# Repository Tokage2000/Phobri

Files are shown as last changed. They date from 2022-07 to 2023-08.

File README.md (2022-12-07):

# Phobri
Repository for a modification of the Phob motherboard to fit an Hori Pad GCC

Potential issues: <br />

LR pads are a bit too small, you may need to glue them/stick them in place if you plan to use them. <br />

You have to cut the inner top of the shell and the start button. <br />
 <br />

Cstick may be awkward to connect. <br />
 <br />

Phob repositories: https://github.com/PhobGCC

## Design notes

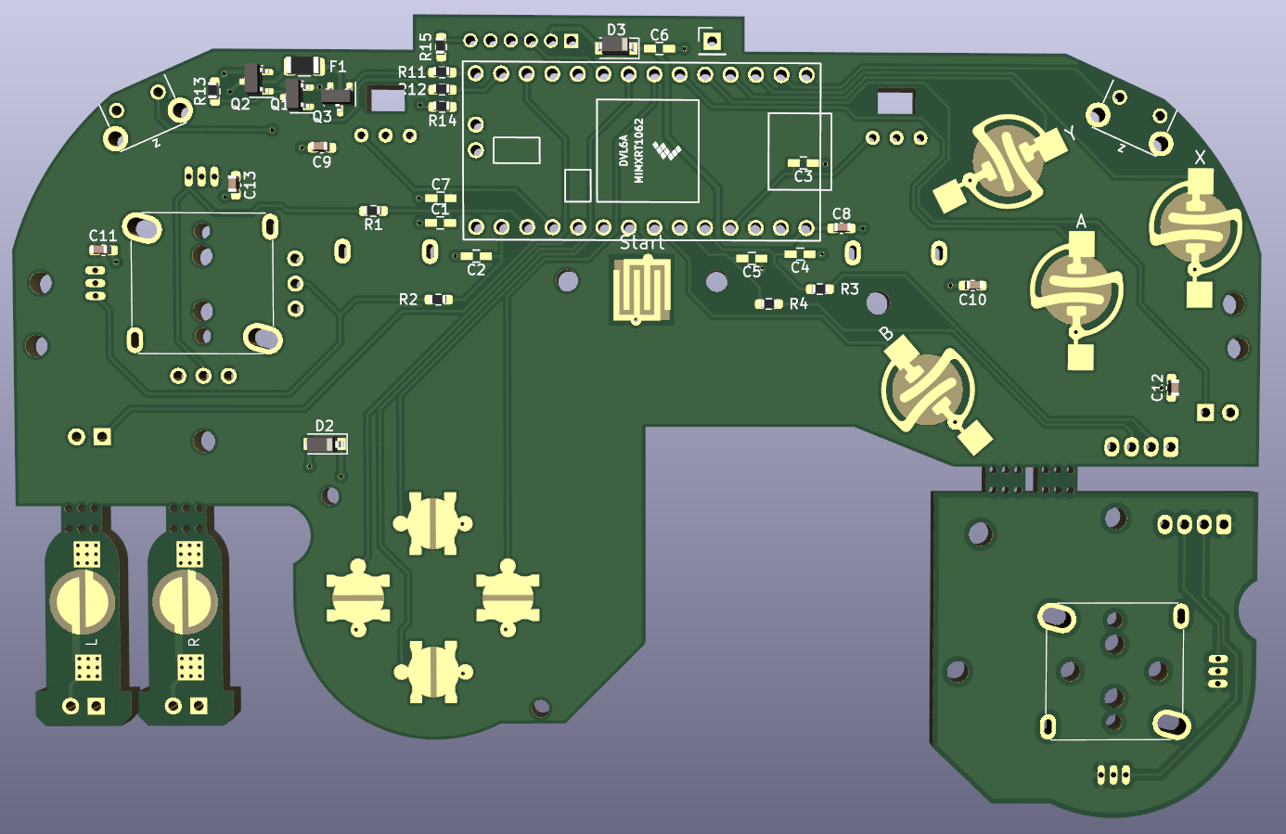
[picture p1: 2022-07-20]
Picture.PNG

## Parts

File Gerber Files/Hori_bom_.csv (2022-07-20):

C1 C2 C3 C4 C5 C7 | 0.047u | C1622 | 6 | https://lcsc.com/product-detail/Multilayer-Ceramic-Capacitors-MLCC-SMD-SMT_Samsung-Electro-Mechanics-CL10B473KB8NNNC_C1622.html
C8 C9 C10 C11 C12 C13 | 1u | C15849 | 6 | https://lcsc.com/product-detail/Multilayer-Ceramic-Capacitors-MLCC-SMD-SMT_Samsung-Electro-Mechanics-CL10A105KB8NNNC_C15849.html
C6 | 10u | C19702 | 1 | https://lcsc.com/product-detail/Multilayer-Ceramic-Capacitors-MLCC-SMD-SMT_Samsung-Electro-Mechanics-CL10A106KP8NNNC_C19702.html
D2 D3 | M7C | C8598 | 2 | https://lcsc.com/product-detail/Schottky-Barrier-Diodes-SBD_Changjiang-Electronics-Tech-CJ-B5819W-SL_C8598.html
F1 | Fuse | C69680 | 1 | https://lcsc.com/product-detail/Resettable-Fuses_TECHFUSE-nSMD020-30V_C69680.html
Q1 Q3 | Q_NMOS_GSD | C20917 | 2 | https://lcsc.com/product-detail/MOSFETs_Alpha-Omega-Semicon-AO3400A_C20917.html
Q2 | Q_PMOS_GDS | C15127 | 1 | https://lcsc.com/product-detail/MOSFETs_Alpha-Omega-Semicon-AO3401A_C15127.html
R11 R12 | 100R | C22775 | 2 | https://lcsc.com/product-detail/Chip-Resistor-Surface-Mount_UNI-ROYAL-Uniroyal-Elec-0603WAF1000T5E_C22775.html
R1 R2 R3 R4 | 2k | C22975 | 4 | https://lcsc.com/product-detail/Chip-Resistor-Surface-Mount_UNI-ROYAL-Uniroyal-Elec-0603WAF2001T5E_C22975.html
R13 R14 R15 | 10k | C25804 | 3 | https://lcsc.com/product-detail/Chip-Resistor-Surface-Mount_UNI-ROYAL-Uniroyal-Elec-0603WAF1002T5E_C25804.html

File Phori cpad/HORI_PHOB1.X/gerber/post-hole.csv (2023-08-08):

Designator | Footprint | Quantity | Value | LCSC Part #
C1, C2, C3 | C_0402_1005Metric | 3 | 100n | C1525
R1, R2 | R_0603_1608Metric_Pad0.98x0.95mm_HandSolder | 2 | 1.1k | C137780
R5, R6, R7, R8 | R_0603_1608Metric_Pad0.98x0.95mm_HandSolder | 4 | 5.6k | C114627
SW1 | SW-TH_L6.2-W6.2-P5.00 | 1 | C_left | C395225
SW2 | SW-TH_L6.2-W6.2-P5.00 | 1 | C_up | C395225
SW3 | SW-TH_L6.2-W6.2-P5.00 | 1 | C_down | C395225
SW4 | SW-TH_L6.2-W6.2-P5.00 | 1 | C_right | C395225

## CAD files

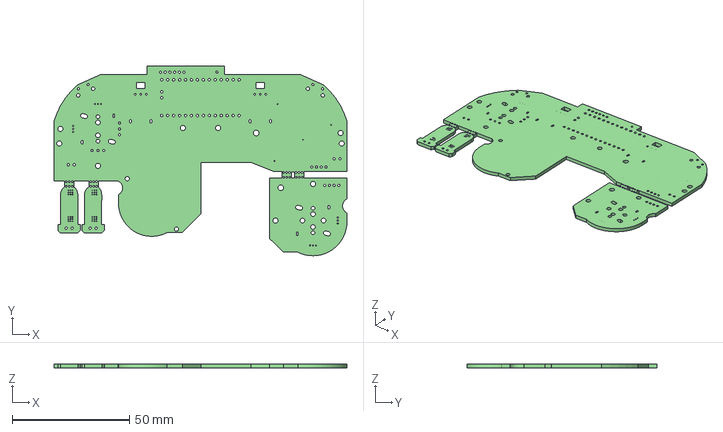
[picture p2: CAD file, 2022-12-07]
KiCad/PhobGCC.step
125.0 x 80.9 x 1.60 mm

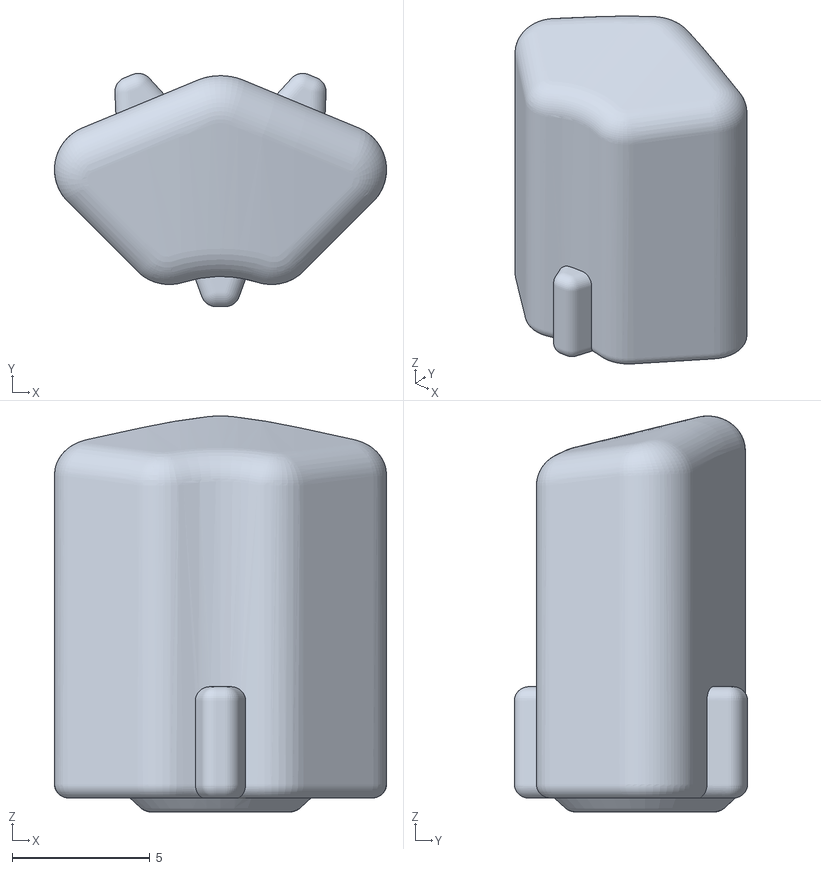
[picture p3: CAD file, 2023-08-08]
Phori cpad/1083v2x1-cpad_button_V2.stl
12.1 x 8.47 x 14.4

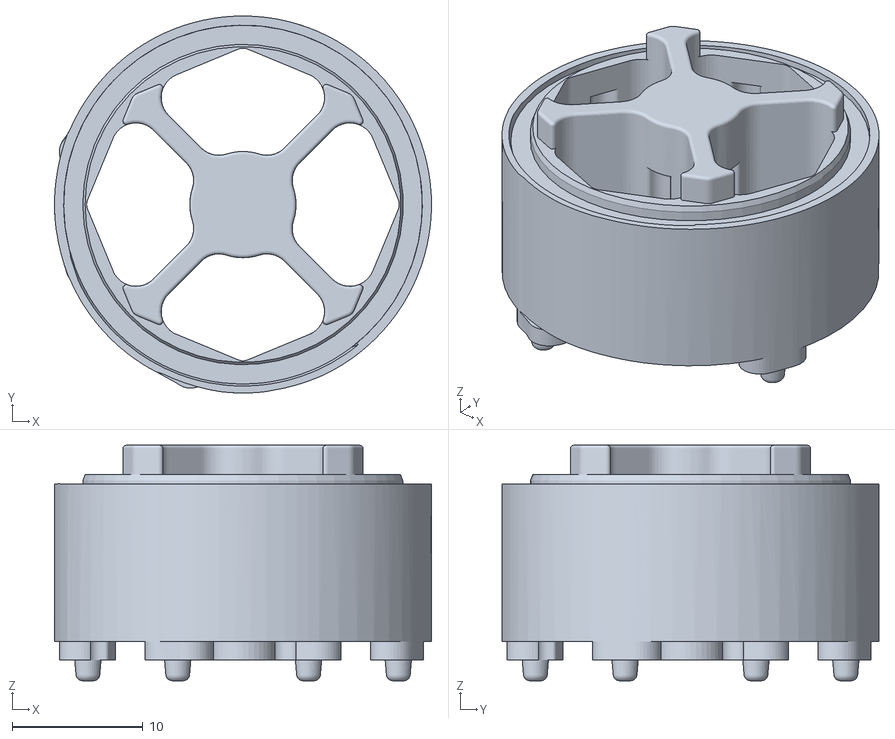
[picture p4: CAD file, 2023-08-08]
Phori cpad/1083-cpad_core.stl
28.8 x 28.8 x 18.0

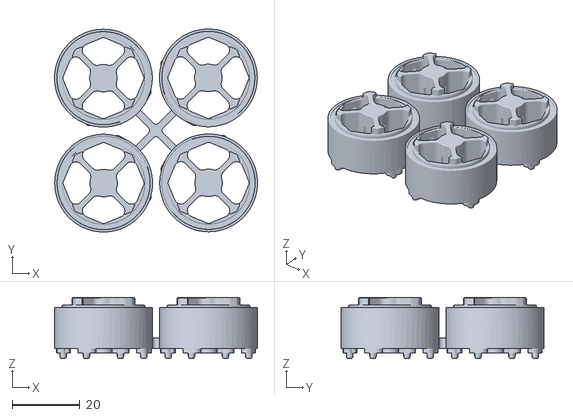
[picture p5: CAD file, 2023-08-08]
Phori cpad/1083x4-cpad_core_x4.stl
59.8 x 59.8 x 18.0

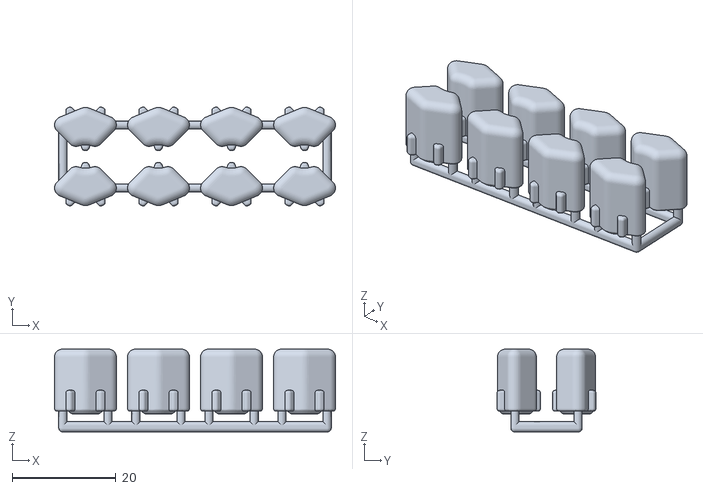
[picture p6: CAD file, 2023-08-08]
Phori cpad/1083 button x8-cpad_button_x8.stl
54.2 x 19.1 x 16.0

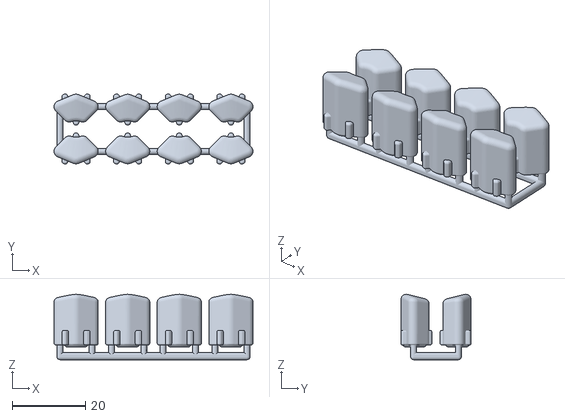
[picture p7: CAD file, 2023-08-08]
Phori cpad/1083v2x8-cpad_button_V2.stl
54.3 x 19.2 x 17.9

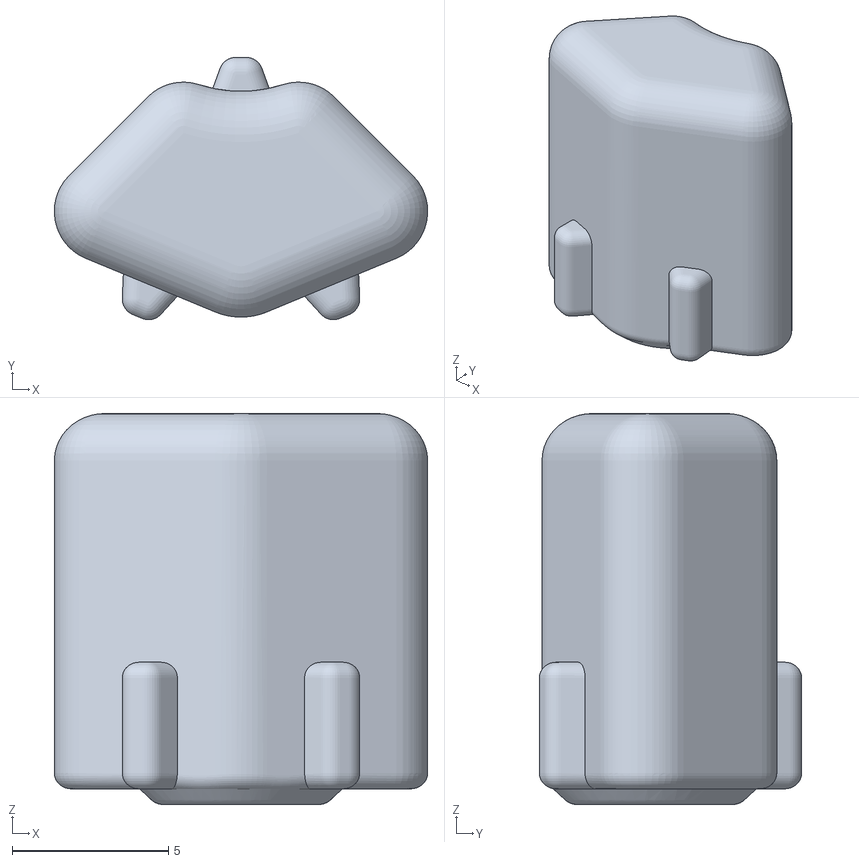
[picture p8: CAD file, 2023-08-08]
Phori cpad/1083 button-cpad_button.stl
11.9 x 8.38 x 12.5

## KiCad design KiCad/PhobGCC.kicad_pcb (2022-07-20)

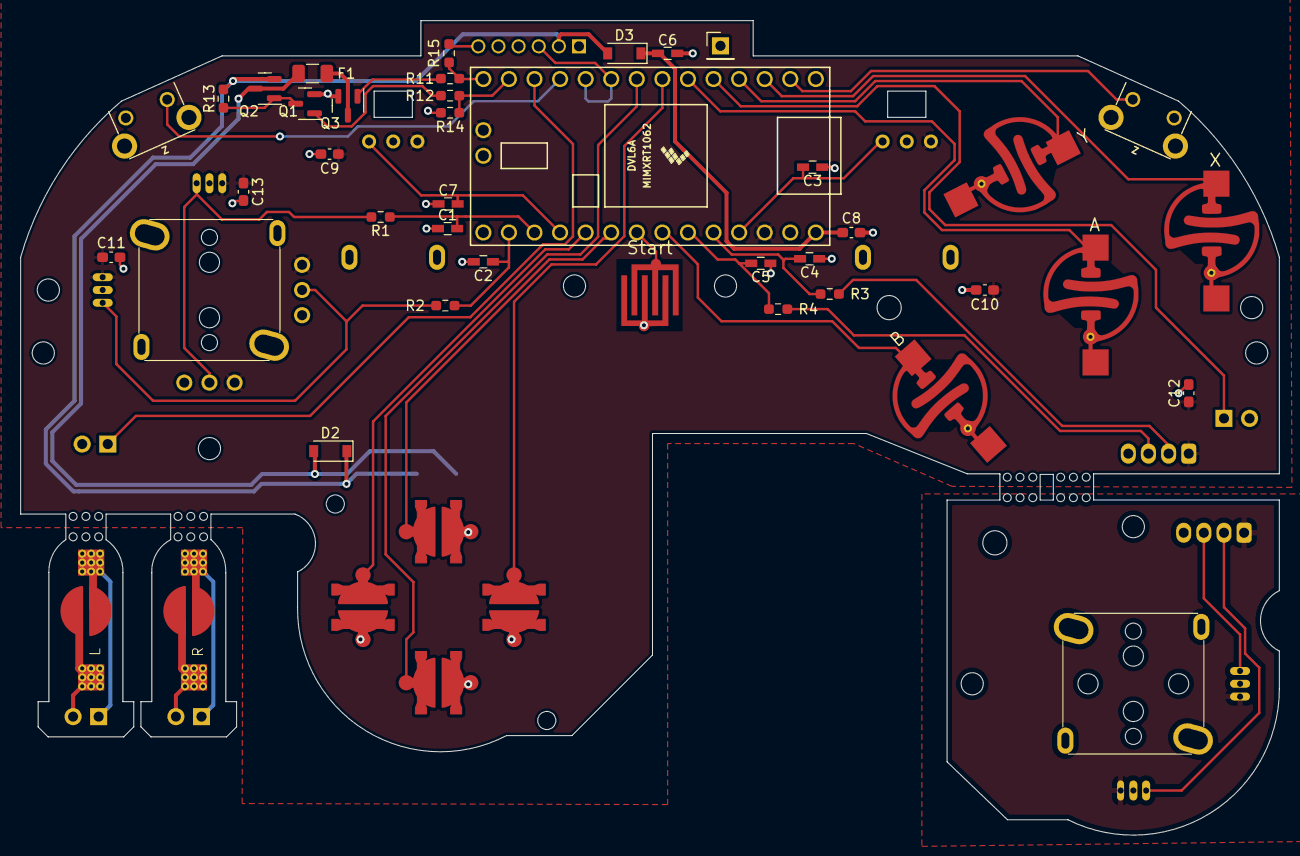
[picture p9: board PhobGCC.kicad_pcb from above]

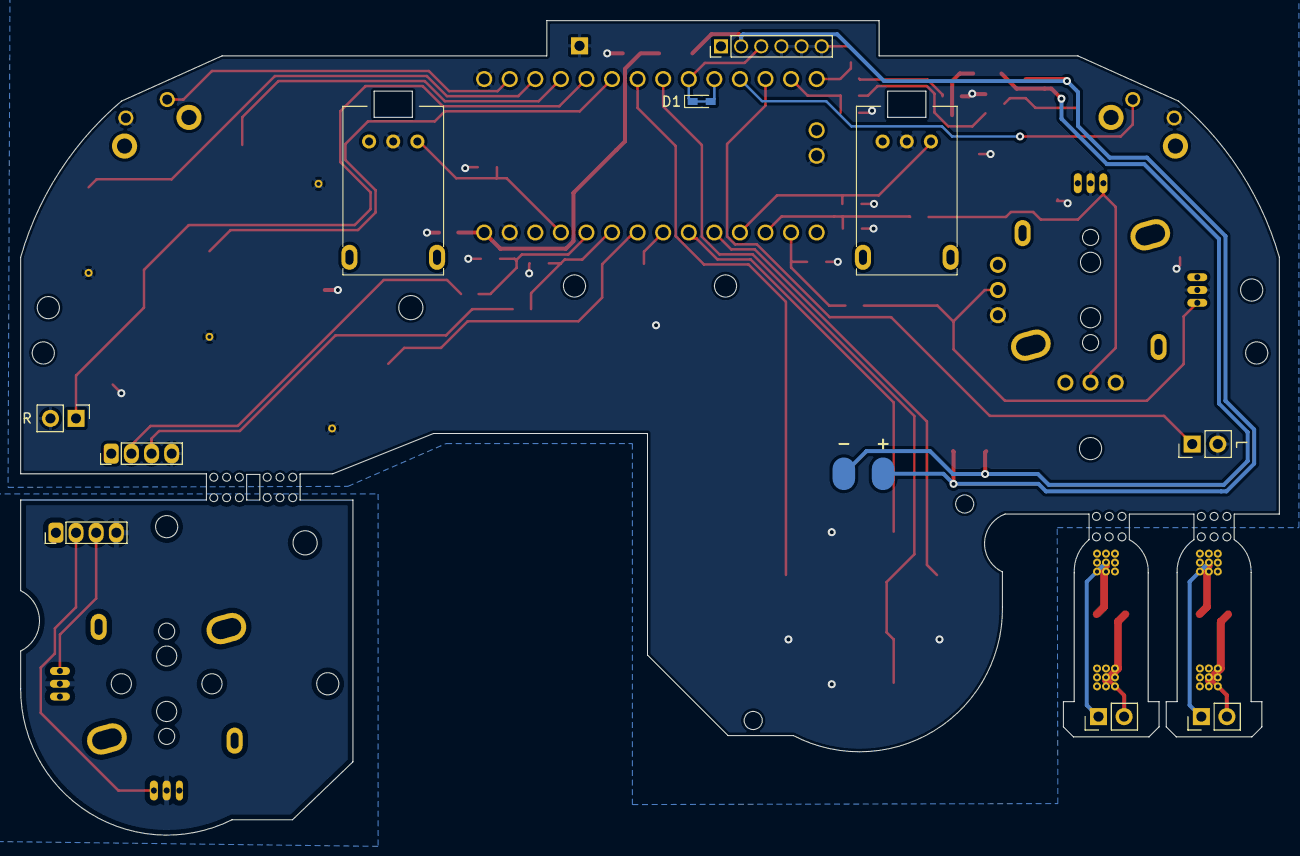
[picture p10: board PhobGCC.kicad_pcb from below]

Board: 2 copper layers, 125.0 x 80.9 mm, 75 parts (13 on the bottom side), 41 nets.

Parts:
C1, C2, C3, C4, C5, C7: 0.047u; C_0603_HandSoldering
C6: 10u; C_0603_HandSoldering
C8, C9, C10, C11, C12, C13: 1u; C_0603_1608Metric_Pad1.08x0.95mm_HandSolder
D1: D_Schottky_Shorted; D_SOD-523_Shorted
D2, D3: M7C; D_SOD-123
F1: Fuse; Fuse_1206_3216Metric
H7, H7#2: 2.4mm; MountingHole_2.4mm
H8, H8#2, H8#3, H8#4, H8#5, H8#6, H8#7, H8#8, H8#9: 2.2mm; MountingHole_2.2mm
H10, H10#2: MountingHole; MountingHole_1.8mm
H12, H13: MountingHole; MountingHole_2.0mm
H14, H15: MouseBite; breakaway-mousebites-double
H16: MouseBiteLA; breakaway-mousebites-double
H17: MouseBiteRA; breakaway-mousebites-double
J1: Conn_01x06_Female; GCC_Header_Straight_1x06_Pitch2.00mm
J2: Conn_01x04_Female; PinHeader_1x04_P2.00mm_Vertical
J3: Conn_01x01_Male; PinHeader_1x01_P2.54mm_Vertical
J4: Conn_01x04_Male; PinHeader_1x04_P2.00mm_Vertical
J5: Rumble; rumble_pins
J6: L; Pin_Header_Straight_1x02_Pitch2.54mm
J7: R; Pin_Header_Straight_1x02_Pitch2.54mm
Q1, Q3: Q_NMOS_GSD; SOT-23
Q2: Q_PMOS_GDS; SOT-23
R1, R2, R3, R4: 2k; R_0603_1608Metric_Pad0.98x0.95mm_HandSolder
R11, R12: 100R; R_0603_1608Metric_Pad0.98x0.95mm_HandSolder
R13, R14, R15: 10k; R_0603_1608Metric_Pad0.98x0.95mm_HandSolder
RV1, RV2: R_POT_MountingPin; GCC_Slider
SW1: A; ABXY_Contact_Omron_Switch
SW2: B; ABXY_Contact_Omron_Switch
SW3: X; ABXY_Contact_Omron_Switch
SW4: Y; ABXY_Contact_Omron_Switch
SW5: Start; Start_Contact
SW6: L; Pin_Header_Straight_1x02_Pitch2.54mm
SW7: R; Pin_Header_Straight_1x02_Pitch2.54mm
SW8, SW8#2: Z; Z_Switch_Edge_Omron
SW9: Dleft; Dpad_Contact_TL3315NF_2
SW10: Dup; Dpad_Contact_TL3315NF_2
SW11: Dright; Dpad_Contact_TL3315NF_2
SW12: Ddown; Dpad_Contact_TL3315NF_2
SW13: L; Trigger_Contact
SW14: R; Trigger_Contact
U1: Teensy4.0; Teensy40_Edge_Pins
U2: 2x DRV5053CAQLPGM Hall Effect Sensors; GCC_Stickbox_2
U5: Stickbox_Assembly; GCC_Stickbox_Hall_Only

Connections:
+3V3: C9.1, C10.1, C11.1, C12.1, C13.1, J2.1, RV1.1 (V+), RV2.1 (V+), U1.16 (3V3), U1.31 (3V3), U2.1 (H1XV), U2.4 (H1YV), U2.15 (P1XV), U2.18 (P1YV)
+5V: D2.1 (K), D3.2 (A), J1.2, J5.1, Q2.2 (S), R13.2
/A: SW1.1, U1.6 (4_BCLK2)
/B: SW2.1, U1.27 (20_A6_TX5_LRCLK1)
/Brake: R12.1, R14.2, U1.13 (11_MOSI_CTX1)
/C_x: J2.2, R3.2
/C_x_filt: C4.1, R3.1, U1.29 (22_A8_CTX1)
/C_y: J2.3, R4.2
/C_y_filt: C5.1, R4.1, U1.28 (21_A7_RX5_BCLK1)
/Data: D1.1 (K), D1.2 (A), J1.3, U1.9 (7_RX2_OUT1A), U1.10 (8_TX2_IN1)
/Ddown: SW12.1, U1.8 (6_OUT1D)
/Dleft: SW9.1, U1.24 (17_A3_TX4_SDA1)
/Dright: SW11.1, U1.7 (5_IN2)
/Dup: SW10.1, U1.25 (18_A4_SDA0)
/L: SW6.1, U1.12 (10_CS_MQSR)
/Lanalog: C7.1, RV1.3 (Signal), U1.23 (16_A2_RX4_SCL1)
/R: SW7.1, U1.5 (3_LRCLK2)
/Ranalog: C3.1, RV2.3 (Signal), U1.30 (23_A9_CRX1_MCLK1)
/Rumble: R11.1, R15.2, U1.14 (12_MISO_MQSL)
/Start: SW5.1, U1.26 (19_A5_SCL0)
/Stick_x: R1.2, U2.3 (H1XS), U2.14 (P1XS)
/Stick_x_filt: C1.1, R1.1, U1.22 (15_A1_RX3_SPDIF_IN)
/Stick_y: R2.2, U2.6 (H1YS), U2.17 (P1YS)
/Stick_y_filt: C2.1, R2.1, U1.21 (14_A0_TX3_SPDIF_OUT)
/X: SW3.1, U1.3 (1_TX1_CTX2_MISO1)
/Y: SW4.1, U1.4 (2_OUT2)
/Z: SW8#2.1, U1.2 (0_RX1_CRX2_CS1)
GND: C1.2, C2.2, C3.2, C4.2, C5.2, C6.2, C7.2, C8.2, C9.2, C10.2, C11.2, C12.2, C13.2, J1.4, J1.5, J1.6, J2.4, J3.1, J4.4, Q1.2 (S), Q3.2 (S), R14.1, R15.1, RV1.2 (GND), RV2.2 (GND), SW1.2, SW2.2, SW3.2, SW4.2, SW5.2, SW6.2, SW7.2, SW8.1, SW8#2.2, SW9.2, SW10.2, SW11.2, SW12.2, U1.1 (GND), U1.17 (GND), U1.32 (GND), U2.2 (H1XG), U2.5 (H1YG), U2.13 (P1XG), U2.16 (P1YG), U5.2 (H1XG), U5.5 (H1YG)
unnamed: C6.1, C8.1, D3.1 (K), U1.33 (VIN)
unnamed: D2.2 (A), F1.1, J5.2, Q2.3 (D)
unnamed: F1.2, Q3.3 (D)
unnamed: J4.2, U5.3 (H1XS)
unnamed: J4.3, U5.6 (H1YS)
unnamed: J6.1, SW13.1
unnamed: J6.2, SW13.2
unnamed: J7.1, SW14.1
unnamed: J7.2, SW14.2
unnamed: Q1.1 (G), R12.2
unnamed: Q1.3 (D), Q2.1 (G), R13.1
unnamed: Q3.1 (G), R11.2
VCC: J4.1, U5.1 (H1XV), U5.4 (H1YV)

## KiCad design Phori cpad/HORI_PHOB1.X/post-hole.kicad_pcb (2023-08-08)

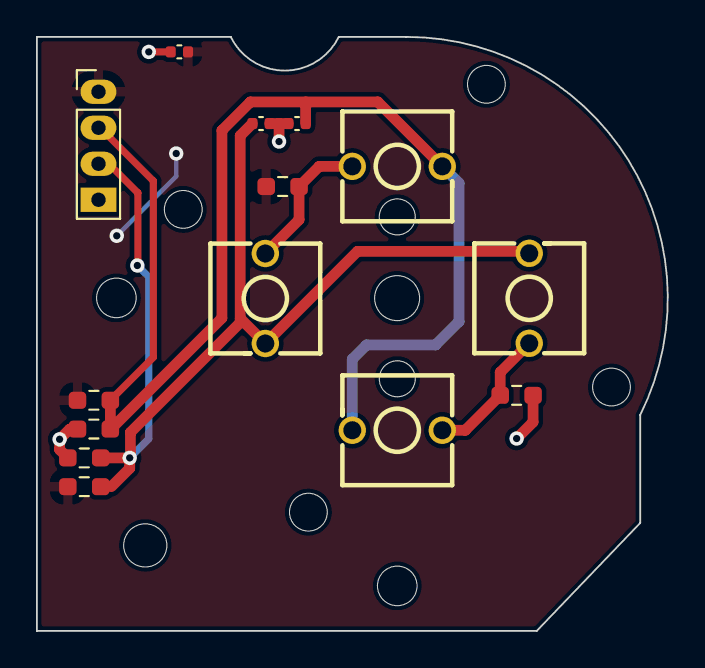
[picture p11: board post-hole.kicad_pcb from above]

Board: 2 copper layers, 35.0 x 33.0 mm, 24 parts (0 on the bottom side), 6 nets.

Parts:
C1, C2, C3: 100n; C_0402_1005Metric
H1, H2, H3, H4: MountingHole; MountingHole_2.1mm
H5: MountingHole; MountingHole_2.5mm
H7: 2.4mm; MountingHole_2.4mm
H8, H8#2: 2.2mm; MountingHole_2.2mm
H12, H12#2: MountingHole; MountingHole_2.0mm
J1: Conn_01x04; PinHeader_1x04_P2.00mm_Vertical
R1, R2: 1.1k; R_0603_1608Metric_Pad0.98x0.95mm_HandSolder
R5, R6, R7, R8: 5.6k; R_0603_1608Metric_Pad0.98x0.95mm_HandSolder
SW1: C_left; SW-TH_L6.2-W6.2-P5.00
SW2: C_up; SW-TH_L6.2-W6.2-P5.00
SW3: C_down; SW-TH_L6.2-W6.2-P5.00
SW4: C_right; SW-TH_L6.2-W6.2-P5.00

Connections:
/C_x: C3.1, J1.2, R7.2, R8.1, SW1.2, SW4.2
/C_y: C2.1, J1.3, R5.2, R6.1, SW2.2, SW3.2
GND: C1.2, C2.2, C3.2, J1.4, R1.2, R6.2, R8.2
unnamed: R1.1, SW1.1, SW3.1
unnamed: R2.1, SW2.1, SW4.1
VCC: C1.1, J1.1, R2.2, R5.1, R7.1

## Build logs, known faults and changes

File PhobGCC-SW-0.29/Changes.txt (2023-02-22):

Changes

Phob1_2Teensy4_0.h:
const int _pinZ2 = 9;

readHardware.h:
pinMode(_pinZ2,INPUT_PULLUP);
hardware.Z = !digitalRead(pin.pinZ) or !digitalRead(pin.pinZ2);

phobGCC.h:
.pinZ2  = _pinZ2,

structsAndEnums.h:
int pinZ2;

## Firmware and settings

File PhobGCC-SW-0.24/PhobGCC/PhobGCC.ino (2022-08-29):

//This software uses bits of code from GoodDoge's Dogebawx project, which was the initial starting point: https://github.com/DogeSSBM/DogeBawx

#include <math.h>
#include <curveFitting.h>
#include <EEPROM.h>
#include <eigen.h>
#include <Eigen/LU>
#include <ADC.h>
#include <VREF.h>
#include <Bounce2.h>
#include "TeensyTimerTool.h"
extern "C" uint32_t set_arm_clock(uint32_t frequency);

//Uncomment the appropriate #include line for your hardware by deleting the two slashes at the beginning of the line.
#include "src/Phob1_2Teensy4_0.h"          // For PhobGCC board 1.2.x with Teensy 4.0

#define BUILD_RELEASE
//#define BUILD_DEV

//This is just an integer.
#define SW_VERSION 24

//#define ENABLE_LED

using namespace Eigen;

TeensyTimerTool::OneShotTimer timer1;

union Buttons{
  uint8_t arr[10];
  struct {

        // byte 0
    uint8_t A : 1;
    uint8_t B : 1;
    uint8_t X : 1;
    uint8_t Y : 1;
    uint8_t S : 1;
    uint8_t orig : 1;
    uint8_t errL : 1;
    uint8_t errS : 1;

    // byte 1
    uint8_t Dl : 1;
    uint8_t Dr : 1;
    uint8_t Dd : 1;
    uint8_t Du : 1;
    uint8_t Z : 1;
    uint8_t R : 1;
    uint8_t L : 1;
    uint8_t high : 1;

    //byte 2-7
    uint8_t Ax : 8;
    uint8_t Ay : 8;
    uint8_t Cx : 8;
    uint8_t Cy : 8;
    uint8_t La : 8;
    uint8_t Ra : 8;

    // magic byte 8 & 9 (only used in origin cmd)
    // have something to do with rumble motor status???
    // ignore these, they are magic numbers needed
    // to make a cmd response work
    uint8_t magic1 : 8;
    uint8_t magic2 : 8;
  };
}btn;

uint8_t hardwareL;
uint8_t hardwareR;
uint8_t hardwareZ;
uint8_t hardwareX;
uint8_t hardwareY;

float _aStickX;
float _aStickY;
float _cStickX;
float _cStickY;


//defining control configuration
int _pinZSwappable = _pinZ;
int _pinXSwappable = _pinX;
int _pinYSwappable = _pinY;
int _jumpConfig = 0;
int _lConfig = 0;
int _rConfig = 0;
int _triggerDefault = 0;
int _lTrigger = 0;
int _rTrigger = 1;
bool _changeTrigger = true;
int _cXOffset = 0;
int _cYOffset = 0;
int _cMax = 127;
int _cMin = -127;
int _LTriggerOffset = 49;
int _RTriggerOffset = 49;
int _triggerMin = 49;
int _triggerMax = 227;
//rumble config; 0 is off, nonzero is on. Higher values are stronger, max 7
int _rumble = 5;
int calcRumblePower(const int rumble){
	return pow(2.0, 7+((rumble+1)/8.0)); //should be 256 when rumble is 7
}
int _rumblePower = calcRumblePower(_rumble);
const int _rumbleMin = 0;
const int _rumbleMax = 7;
const int _rumbleDefault = 5;
bool _safeMode = true;
bool _autoInit = false;

int trigL,trigR;

///// Values used for adjusting snapback in the CarVac Filter

int _xSnapback = 4;
int _ySnapback = 4;
const float _snapbackMin = 0;
const float _snapbackMax = 10;
const float _snapbackDefault = 4;//0 disables the filter completely, 4 is the default
float velDampFromSnapback(const int snapback){
	return 0.125 * pow(2, (snapback-4)/3.0);//4 should yield 0.125, 10 should yield 0.5, don't care about 0
}

// Values used for dealing with X/Y Smoothing in the CarVac Filter, for ledge-dashing
// also used for C-stick snapback filtering

float _smoothingMin = 0.0;
float _smoothingMax = 0.9;

//New snapback Kalman filter parameters.
struct FilterGains {
	//What's the max stick distance from the center
	float maxStick;
	//filtered velocity terms
	//how fast the filtered velocity falls off in the absence of stick movement.
	//Probably don't touch this.
	float xVelDecay;//0.1 default for 1.2ms timesteps, larger for bigger timesteps
	float yVelDecay;
	//how much the current position disagreement impacts the filtered velocity.
	//Probably don't touch this.
	float xVelPosFactor;//0.01 default for 1.2ms timesteps, larger for bigger timesteps
	float yVelPosFactor;
	//how much to ignore filtered velocity when computing the new stick position.
	//DO CHANGE THIS
	//Higher gives shorter rise times and slower fall times (more pode, less snapback)
	float xVelDamp;//0.125 default for 1.2ms timesteps, smaller for bigger timesteps
	float yVelDamp;
	//speed and accel thresholds below which we try to follow the stick better
	//These may need tweaking according to how noisy the signal is
	//If it's noisier, we may need to add additional filtering
	//If the timesteps are *really small* then it may need to be increased to get
	//  above the noise floor. Or some combination of filtering and playing with
	//  the thresholds.
	float velThresh;//1 default for 1.2ms timesteps, larger for bigger timesteps
	float accelThresh;//5 default for 1.2ms timesteps, larger for bigger timesteps
	//This just applies a low-pass filter.
	//The purpose is to provide delay for single-axis ledgedashes.
	//Must be between 0 and 1. Larger = more smoothing and delay.
	float xSmoothing;
	float ySmoothing;
	//Same thing but for C-stick
	float cXSmoothing;
	float cYSmoothing;
};
FilterGains _gains {//these values are actually timestep-compensated for in runKalman
    .maxStick = 100,
    .xVelDecay = 0.1,
    .yVelDecay = 0.1,
    .xVelPosFactor = 0.01,
    .yVelPosFactor = 0.01,
    .xVelDamp = 0.125,
    .yVelDamp = 0.125,
    .velThresh = 1.00,
    .accelThresh = 3.00,
    .xSmoothing = 0.0,
    .ySmoothing = 0.0,
    .cXSmoothing = 0.0,
    .cYSmoothing = 0.0
};
FilterGains _g;//this gets filled by recomputeGains();

//////values used to determine how much large of a region will count as being "in a notch"

const float _marginAngle = 1.50/100.0; //angle range(+/-) in radians that will be collapsed down to the ideal angle
const float _tightAngle = 0.1/100.0;//angle range(+/-) in radians that the margin region will be collapsed down to, found that having a small value worked better for the transform than 0

//////values used for calibration
const int _analogCenter = 127;
const int _noOfNotches = 16;
const int _noOfCalibrationPoints = _noOfNotches * 2;
const int _noOfAdjNotches = 12;
float _ADCScale = 1;
float _ADCScaleFactor = 1;
const int _notCalibrating = -1;
const float _maxStickAngle = 0.4886921906;//28 degrees; this is the max angular deflection of the stick.
bool	_calAStick = true; //determines which stick is being calibrated (if false then calibrate the c-stick)
bool _advanceCal = false;
bool _advanceCalPressed = false;
bool _undoCal = false;
bool _undoCalPressed = false;
int _currentCalStep; //keeps track of which caliblration step is active, -1 means calibration is not running
bool _notched = false; //keeps track of whether or not the controller has firefox notches
const int _calibrationPoints = _noOfNotches+1; //number of calibration points for the c-stick and a-stick for a controller without notches
float _cleanedPointsX[_noOfNotches+1]; //array to hold the x coordinates of the stick positions for calibration
float _cleanedPointsY[_noOfNotches+1]; //array to hold the y coordinates of the stick positions for calibration
float _notchPointsX[_noOfNotches+1]; //array to hold the x coordinates of the notches for calibration
float _notchPointsY[_noOfNotches+1]; //array to hold the x coordinates of the notches for calibration
//                                                         right                     notch 1                   up right                  notch 2                   up                        notch 3                   up left                   notch 4                   left                      notch 5                   down left                 notch 6                   down                      notch 7                   down right                notch 8
//                                                         0            1            2            3            4            5            6            7            8            9            10           11           12           13           14           15           16           17           18           19           20           21           22           23           24           25           26           27           28           29           30           31

const float _defaultCalPointsX[_noOfCalibrationPoints] = {0.3010610568,0.3603937084,0.3010903951,0.3000194135,0.3005567843,0.3471911134,0.3006904343,0.3009976295,0.3000800899,0.300985051, 0.3001020858,0.300852804, 0.3008746305,0.2548450139,0.3001434092,0.3012600593,0.3011594091,0.2400535218,0.3014621077,0.3011248469,0.3010860944,0.2552106305,0.3002197989,0.3001679513,0.3004438517,0.300486505, 0.3002766984,0.3012828579,0.3014959877,0.346512936, 0.3013398149,0.3007809916};
const float _defaultCalPointsY[_noOfCalibrationPoints] = {0.300092277, 0.3003803475,0.3002205792,0.301004752, 0.3001241394,0.3464200104,0.3001331245,0.3011881186,0.3010685972,0.3606900641,0.3001520488,0.3010662947,0.3008837105,0.3461478452,0.3011732026,0.3007367683,0.3011345742,0.3000566197,0.3006843288,0.3009673425,0.3011228978,0.2547579852,0.3011177285,0.301264851, 0.3002376991,0.2403885431,0.3006540818,0.3010588401,0.3011093054,0.2555000655,0.300080276, 0.3008482317};
//                                                         right        up          left          down         up right     up left      down left    down right   notch 1      notch 2      notch 3      notch 4      notch 5      notch 6      notch 7      notch 8
const int _calOrder[_noOfCalibrationPoints] =             {0, 1,        8, 9,       16, 17,       24, 25,      4, 5,        12, 13,      20, 21,      28, 29,      2, 3,        6, 7,        10, 11,      14, 15,      18, 19,      22, 23,      26, 27,      30, 31};
//                                                         right        notch 1      up right     notch 2      up           notch 3      up left      notch 4      left         notch 5      down left    notch 6      down         notch 7      down right   notch 8
//                                                         0            1            2            3            4            5            6            7            8            9            10           11           12           13           14           15
const float _notchAngleDefaults[_noOfNotches] =           {0,           M_PI/8.0,    M_PI*2/8.0,  M_PI*3/8.0,  M_PI*4/8.0,  M_PI*5/8.0,  M_PI*6/8.0,  M_PI*7/8.0,  M_PI*8/8.0,  M_PI*9/8.0,  M_PI*10/8.0, M_PI*11/8.0, M_PI*12/8.0, M_PI*13/8.0, M_PI*14/8.0, M_PI*15/8.0};
//const float _notchRange[_noOfNotches] =                   {0,           M_PI*1/16.0, M_PI/16.0,   M_PI*1/16.0, 0,           M_PI*1/16.0, M_PI/16.0,   M_PI*1/16.0, 0,           M_PI*1/16.0, M_PI/16.0,   M_PI*1/16.0, 0,           M_PI*1/16.0, M_PI/16.0,   M_PI*1/16.0};
const float _notchAdjustStretchLimit = 0.3;
float _aNotchAngles[_noOfNotches] =                       {0,           M_PI/8.0,    M_PI*2/8.0,  M_PI*3/8.0,  M_PI*4/8.0,  M_PI*5/8.0,  M_PI*6/8.0,  M_PI*7/8.0,  M_PI*8/8.0,  M_PI*9/8.0,  M_PI*10/8.0, M_PI*11/8.0, M_PI*12/8.0, M_PI*13/8.0, M_PI*14/8.0, M_PI*15/8.0};
float _measuredNotchAngles[_noOfNotches];
const int _notchStatusDefaults[_noOfNotches] =            {3,           1,           2,           1,           3,           1,           2,           1,           3,           1,           2,           1,           3,           1,           2,           1};
int _aNotchStatus[_noOfNotches] =                         {3,           1,           2,           1,           3,           1,           2,           1,           3,           1,           2,           1,           3,           1,           2,           1};
int _cNotchStatus[_noOfNotches] =                         {3,           1,           2,           1,           3,           1,           2,           1,           3,           1,           2,           1,           3,           1,           2,           1};
float _cNotchAngles[_noOfNotches];
//                                                         up right     up left      down left    down right   notch 1      notch 2      notch 3      notch 4      notch 5      notch 6      notch 7      notch 8
const int _notchAdjOrder[_noOfAdjNotches] =               {2,           6,           10,          14,          1,           3,           5,           7,           9,           11,          13,          15};
const int _cardinalNotch = 3;
const int _secondaryNotch = 2;
const int _tertiaryNotchActive = 1;
const int _tertiaryNotchInactive = 0;
const int _fitOrder = 3; //fit order used in the linearization step
float _aFitCoeffsX[_fitOrder+1]; //coefficients for linearizing the X axis of the a-stick
float _aFitCoeffsY[_fitOrder+1]; //coefficients for linearizing the Y axis of the a-stick
float _cFitCoeffsX[_fitOrder+1]; //coefficients for linearizing the Y axis of the c-stick
float _cFitCoeffsY[_fitOrder+1]; //coefficients for linearizing the Y axis of the c-stick
float _aAffineCoeffs[_noOfNotches][6]; //affine transformation coefficients for all regions of the a-stick
float _cAffineCoeffs[_noOfNotches][6]; //affine transformation coefficients for all regions of the c-stick
float _aBoundaryAngles[_noOfNotches]; //angles at the boundaries between regions of the a-stick
float _cBoundaryAngles[_noOfNotches]; //angles at the boundaries between regions of the c-stick
float _tempCalPointsX[(_noOfNotches)*2]; //temporary storage for the x coordinate points collected during calibration before the are cleaned and put into _cleanedPointsX
float _tempCalPointsY[(_noOfNotches)*2]; //temporary storage for the y coordinate points collected during calibration before the are cleaned and put into _cleanedPointsY
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
void loop() {
	//check if we should be reporting values yet
	if((btn.B || _autoInit) && !_running){
		Serial.println("Starting to report values");
		_running=true;
	}

	//read the controllers buttons
	readButtons();

	//check to see if we are calibrating
	if(_currentCalStep >= 0){
		if(_calAStick){
			if(_currentCalStep >= _noOfCalibrationPoints){//adjust notch angles
				adjustNotch(_currentCalStep, _dT, hardwareY, hardwareX, btn.B, true, _measuredNotchAngles, _aNotchAngles, _aNotchStatus);
				if(hardwareY || hardwareX || (btn.B)){//only run this if the notch was adjusted
					//clean full cal points again, feeding updated angles in
					cleanCalPoints(_tempCalPointsX, _tempCalPointsY, _aNotchAngles, _cleanedPointsX, _cleanedPointsY, _notchPointsX, _notchPointsY, _aNotchStatus);
					//linearize again
					linearizeCal(_cleanedPointsX, _cleanedPointsY, _cleanedPointsX, _cleanedPointsY, _aFitCoeffsX, _aFitCoeffsY);
					//notchCalibrate again to update the affine transform
					notchCalibrate(_cleanedPointsX, _cleanedPointsY, _notchPointsX, _notchPointsY, _noOfNotches, _aAffineCoeffs, _aBoundaryAngles);
				}
			}else{//just show desired stick position
				displayNotch(_currentCalStep, true, _notchAngleDefaults);
			}
			readSticks(true,false);
		}
		else{
			if(_currentCalStep >= _noOfCalibrationPoints){//adjust notch angles
				adjustNotch(_currentCalStep, _dT, hardwareY, hardwareX, btn.B, false, _measuredNotchAngles, _cNotchAngles, _cNotchStatus);
				if(hardwareY || hardwareX || (btn.B)){//only run this if the notch was adjusted
					//clean full cal points again, feeding updated angles in
					cleanCalPoints(_tempCalPointsX, _tempCalPointsY, _cNotchAngles, _cleanedPointsX, _cleanedPointsY, _notchPointsX, _notchPointsY, _cNotchStatus);
					//linearize again
					linearizeCal(_cleanedPointsX, _cleanedPointsY, _cleanedPointsX, _cleanedPointsY, _cFitCoeffsX, _cFitCoeffsY);
					//notchCalibrate again to update the affine transform
					notchCalibrate(_cleanedPointsX, _cleanedPointsY, _notchPointsX, _notchPointsY, _noOfNotches, _cAffineCoeffs, _cBoundaryAngles);
				}
			}else{//just show desired stick position
				displayNotch(_currentCalStep, false, _notchAngleDefaults);
			}
			readSticks(false,true);
		}
	}
	else if(_running){
		//if not calibrating read the sticks normally
		readSticks(true,true);
	}
}

#ifdef TEENSY4_0
#ifndef HALFDUPLEX
//commInt() will be called on every rising edge of a pulse that we receive
//we will check if we have the expected amount of serial data yet, if we do we will do something with it, if we don't we will do nothing and wait for the next rising edge to check again
void commInt() {
	//check to see if we have the expected amount of data yet
	if(Serial2.available() >= _bitQueue){
		//check to see if we have been writing data, if have then we need to clear it and set the serial port back to low speed to be ready to receive the next command
		if(_writing){
			//Set pin 13 (LED) low for debugging, if it flickers it means the teensy got stuck here somewhere
			digitalWriteFast(_pinLED,LOW);
			//wait for the stop bit to be read

			while(Serial2.available() <= _bitQueue){}
			//check to see if we just reset reportCount to 0, if we have then we will report the data we just sent over to the PC over serial
			if(_reportCount == 0){
				char myBuffer[128];
				for(int i = 0; i < _bitQueue+1; i++){
					myBuffer[i] = (Serial2.read() > 0b11110000)+48;
				}
				//Serial.print("Sent: ");
				//Serial.write(myBuffer,_bitQueue+1);
				//Serial.println();
			}

			//flush and clear the any remaining data just to be sure
			Serial2.flush();
			Serial2.clear();

			//turn the writing flag off, set the serial port to low speed, and set our expected bit queue to 8 to be ready to receive our next command
			_writing = false;
			Serial2.begin(_slowBaud);
			_bitQueue = 8;
		}
		//if we are not writing, check to see if we were waiting for a poll command to finish
		//if we are, we need to clear the data and send our poll response
		else if(_waiting){
			digitalWriteFast(_pinLED,LOW);
			//wait for the stop bit to be received
			while(Serial2.available() <= _bitQueue){}
#ifdef ENABLE_LED
			digitalWriteFast(_pinLED,HIGH);
#endif //ENABLE_LED
			//check to see if we just reset reportCount to 0, if we have then we will report the remainder of the poll response to the PC over serial
			if(_reportCount == 0){
				Serial.print("Poll: ");
				char myBuffer[128];
				for(int i = 0; i < _bitQueue+1; i++){
					myBuffer[i] = (Serial2.read() > 0b11110000)+48;
				}
				//Serial.write(myBuffer,_bitQueue+1);
				//Serial.println();
			}

			//clear any remaining data
			Serial2.clear();

			//clear any remaining data, set the waiting flag to false, and set the serial port to high speed to be ready to send our poll response
			Serial2.clear();
			_waiting = false;
			setFastBaud();

			//set the writing flag to true, set our expected bit queue to the poll response length -1 (to account for the stop bit)
			_writing = true;
			_bitQueue = _pollLength/2;

			//write the poll response
			for(int i = 0; i<_pollLength; i += 2){
				if(_commResponse[i] != 0 && _commResponse[i+1] != 0){
					//short low period = 1
					//long low period = 0
					Serial2.write(0xEF);
				} else if (_commResponse[i] == 0 && _commResponse[i+1] != 0){
					Serial2.write(0xE8);
				} else if (_commResponse[i] != 0 && _commResponse[i+1] == 0){
					Serial2.write(0x0F);
				} else if (_commResponse[i] == 0 && _commResponse[i+1] == 0){
					Serial2.write(0x08);
				}
			}
			//write stop bit to indicate end of response
			Serial2.write(0xFF);
		}
		else{
			//We are not writing a response or waiting for a poll response to finish, so we must have received the start of a new command
			//Set pin 13 (LED) low for debugging, if it flickers it means the teensy got stuck here somewhere
			digitalWriteFast(_pinLED,LOW);

			//increment the report count, will be used to only send a report every 64 commands to not overload the PC serial connection
			_reportCount++;
			if(_reportCount > 64){
				_reportCount = 0;
			}

			//clear the command byte of previous data
			_cmdByte = 0;

			//write the new data from the serial buffer into the command byte
			for(int i = 0; i<8; i++){
				_cmdByte = (_cmdByte<<1) | (Serial2.read() > 0b11110000);

			}

			//if we just reset reportCount, report the command we received and the number of strange commands we've seen so far over serial
			//if(_reportCount==0){
				//Serial.print("Received: ");
				//Serial.println(_cmdByte,BIN);
				//Serial.print("Error Count:");
				//Serial.println(_errorCount);
			//}

			//if the command byte is all 0s it is probe command, we will send a probe response
			if(_cmdByte == 0b00000000){
				//wait for the stop bit to be received and clear it
				while(!Serial2.available()){}
				Serial2.clear();

				//switch the hardware serial to high speed for sending the response, set the _writing flag to true, and set the expected bit queue length to the probe response length minus 1 (to account for the stop bit)
				setFastBaud();
				_writing = true;
				_bitQueue = _probeLength/2;

				//write the probe response
				for(int i = 0; i<_probeLength; i += 2){
					if(_probeResponse[i] != 0 && _probeResponse[i+1] != 0){
						//short low period = 1
						//long low period = 0
						Serial2.write(0xEF);
					} else if (_probeResponse[i] == 0 && _probeResponse[i+1] != 0){
						Serial2.write(0xE8);
					} else if (_probeResponse[i] != 0 && _probeResponse[i+1] == 0){
						Serial2.write(0x0F);
					} else if (_probeResponse[i] == 0 && _probeResponse[i+1] == 0){
						Serial2.write(0x08);
					}
				}
				//write stop bit to indicate end of response
				Serial2.write(0xFF);
			}
			//if the command byte is 01000001 it is an origin command, we will send an origin response
			else if(_cmdByte == 0b01000001){
				//wait for the stop bit to be received and clear it
				while(!Serial2.available()){}
				Serial2.clear();

				//switch the hardware serial to high speed for sending the response, set the _writing flag to true, and set the expected bit queue length to the origin response length minus 1 (to account for the stop bit)
				setFastBaud();
				_writing = true;
				_bitQueue = _originLength/2;
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

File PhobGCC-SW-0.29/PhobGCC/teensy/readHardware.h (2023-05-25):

#ifndef READHARDWARE_H
#define READHARDWARE_H

//include this after the pins are defined in the Teensy board-specific headers

#include <ADC.h>
#include <VREF.h>
#include "../common/structsAndEnums.h"

ADC *adc = new ADC();

void setPinModes(){
	pinMode(_pinL,INPUT_PULLUP);
	pinMode(_pinR,INPUT_PULLUP);
	pinMode(_pinDr,INPUT_PULLUP);
	pinMode(_pinDu,INPUT_PULLUP);
	pinMode(_pinDl,INPUT_PULLUP);
	pinMode(_pinDd,INPUT_PULLUP);
	pinMode(_pinX,INPUT_PULLUP);
	pinMode(_pinY,INPUT_PULLUP);

	pinMode(_pinA,INPUT_PULLUP);
	pinMode(_pinB,INPUT_PULLUP);
	pinMode(_pinZ,INPUT_PULLUP);
	pinMode(_pinZ2,INPUT_PULLUP);
	pinMode(_pinS,INPUT_PULLUP);
#ifdef TEENSY4_0
#ifdef HALFDUPLEX
	pinMode(_pinRX,INPUT_PULLUP);
#else // HALFDUPLEX
	pinMode(9,    INPUT_PULLUP); //the normal RX pin doesn't work on teensy 4 with full duplex
#endif // HALFDUPLEX
	pinMode(_pinLED,   OUTPUT);
#endif // TEENSY4_0

#ifdef RUMBLE
	pinMode(_pinRumble, OUTPUT);
	pinMode(_pinBrake, OUTPUT);
#endif

	//Teensy 4 has some weird jump in the analog with default pin mode
	pinMode(_pinLa,INPUT_DISABLE);
	pinMode(_pinRa,INPUT_DISABLE);
	pinMode(_pinAx,INPUT_DISABLE);
	pinMode(_pinAy,INPUT_DISABLE);
	pinMode(_pinCx,INPUT_DISABLE);
	pinMode(_pinCy,INPUT_DISABLE);
}

void readButtons(const Pins &pin, Buttons &hardware) {
	hardware.A = !digitalRead(pin.pinA);
	hardware.B = !digitalRead(pin.pinB);
	hardware.X = !digitalRead(pin.pinX);
	hardware.Y = !digitalRead(pin.pinY);
	hardware.L = !digitalRead(pin.pinL);
	hardware.R = !digitalRead(pin.pinR);
	hardware.Z = !digitalRead(pin.pinZ) or !digitalRead(pin.pinZ2);
	hardware.S = !digitalRead(pin.pinS);
	hardware.Du = !digitalRead(pin.pinDu);
	hardware.Dd = !digitalRead(pin.pinDd);
	hardware.Dl = !digitalRead(pin.pinDl);
	hardware.Dr = !digitalRead(pin.pinDr);
}

void readADCScale(float &ADCScale, float ADCScaleFactor) {
#ifdef USEADCSCALE
	ADCScale = ADCScale*0.999 + ADCScaleFactor/adc->adc1->analogRead(ADC_INTERNAL_SOURCE::VREF_OUT);
#endif
	// otherwise _ADCScale is 1
}

//these are 12 bit but we right shift to get 8 bit
//implement a 3 unit deadzone
int readLa(const Pins &pin, const int initial, const float scale) {
	float temp = (adc->adc0->analogRead(pin.pinLa)) / 16.0;
	if(temp < 3) {
		temp = 0.0f;
	}
	return (uint8_t) min(255, max(0, temp - initial) * scale);
}
int readRa(const Pins &pin, const int initial, const float scale) {
	float temp = (adc->adc0->analogRead(pin.pinRa)) / 16.0;
	if(temp < 3) {
		temp = 0.0f;
	}
	return (uint8_t) min(255, max(0, temp - initial) * scale);
}

//these are native 12-bit
int readAx(const Pins &pin) {
	return adc->adc0->analogRead(pin.pinAx);
}
int readAy(const Pins &pin) {
	return adc->adc0->analogRead(pin.pinAy);
}
int readCx(const Pins &pin) {
	return adc->adc0->analogRead(pin.pinCx);
}
int readCy(const Pins &pin) {
	return adc->adc0->analogRead(pin.pinCy);
}

#endif //READHARDWARE_H

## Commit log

2022-07-20 Version 1
    [Hori_bom_.csv, PhobGCC.kicad_pcb, PhobGCC.kicad_sch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]
2022-07-20 Update README.md
    Added a list of currently known issues or potential issues
2022-08-29 Added a mod of the 0.24 Phob SW with the Hori Z button set to Z
2023-08-08 added the hori cpad files
    [1083 button x8-cpad_button_x8.stl, 1083 button-cpad_button.stl, 1083-cpad_core.stl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]
